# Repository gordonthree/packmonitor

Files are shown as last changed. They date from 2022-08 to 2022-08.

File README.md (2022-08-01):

# Smart battery power monitor project

### A slim circuit board for managing charge and discharge of multi-cell LiFePo4 battery packs. Intended to track state of charge by coulomb counting and prevent battery pack damage from over discharge, over current and over temperature conditions.

## Goals:

1. Monitor and record total amperage in and out
2. Monitor and record temperature, ideally three places
3. Monitor and record pack voltage
4. Provide under-voltage disconnect
5. Provide over-temperature disconnect

## Features:
1. Atmel AVR Micro: ATMEGA4808 TQFP-32
1. Hall effect current sensor: TMCS1108
   * Check my inventory for ACS7xx sensors!
3. FRAM data storage : I2C FM24C64B
4. Precision ADC: I2C NAU7802
5. Hot swap buffer: I2C TCA4311a, PCA9508
1. Host side i2c mux: PCA9545A
6. Max PCB width 18mm
7. Precision fixed resistor for thermistors?
   * Thermistors: NRL1504F3950B1F
   * Thermistors connect to uC ADC
8. Power selector IC: AP2411
9. Low Iq power supply for battery side, switching or linear?
10. SMT button for battiery status

## Connectors:

1. Battery side
   * Battery In and Out (14 ga) - WAGO screw cage
   * 6-pin jst-xh vertical for three thermistors
1. Upstream interface: I2C
   * JST-xh 6-pin connector +5v, GND, SCL, GND, SDA, GND
   * TCA4311 on battery side
   * I2C switch on host side (might not need)

## Indicators:

1. Bus controlled:
   * Bus power (from vcc)
   * Bus active (from CS line)
2. uC controlled:
   * Battery SOC (three leds)
   * Battery health (red/green)

## Client Commands:

* See registers.md for addressing and more details

## Questions:

1. Data logging without a RTC?
  * Chip seems to keep time well enough with occasional updates from master
1. High side or low side disconnect?

## Resources:

#### ATMega4808:

* [https://www.digikey.com/en/products/detail/microchip-technology/ATMEGA4808-AUR/10444912](https://www.digikey.com/en/products/detail/microchip-technology/ATMEGA4808-AUR/10444912)
* [https://ww1.microchip.com/downloads/en/DeviceDoc/ATmega4808-09-DataSheet-DS40002173C.pdf](https://ww1.microchip.com/downloads/en/DeviceDoc/ATmega4808-09-DataSheet-DS40002173C.pdf)
* [https://github.com/MCUdude/MegaCoreX#pinout](https://github.com/MCUdude/MegaCoreX#pinout)

#### Thermistor:

* [https://www.digikey.com/en/products/detail/eaton-electronics-division/NRL1504F3950B1F/15927588](https://www.digikey.com/en/products/detail/eaton-electronics-division/NRL1504F3950B1F/15927588)
* [https://www.maximintegrated.com/en/design/technical-documents/app-notes/1/1753.html](https://www.maximintegrated.com/en/design/technical-documents/app-notes/1/1753.html)
* [https://www.jameco.com/Jameco/workshop/TechTip/temperature-measurement-ntc-thermistors.html](https://www.jameco.com/Jameco/workshop/TechTip/temperature-measurement-ntc-thermistors.html)

#### Readng precise voltages:

* [https://skillbank.co.uk/arduino/measure.htm](https://skillbank.co.uk/arduino/measure.htm)

#### ATMEGA Arduino:

* [https://github.com/MCUdude/MegaCoreX](https://github.com/MCUdude/MegaCoreX)

#### AVR DA / DB / DD Series:

* [https://github.com/SpenceKonde/DxCore](https://github.com/SpenceKonde/DxCore)
#### Bootloader:

* [https://github.com/Optiboot/optiboot](https://github.com/Optiboot/optiboot)

#### FRAM:

* [FM24C64B](https://www.digikey.com/en/products/detail/cypress-semiconductor-corp/FM24C64B-GTR/3788931)

#### Hall Effect Sensor:

* [https://www.ti.com/product/TMCS1108](https://www.ti.com/product/TMCS1108)

#### Hot swap buffers:

* [https://www.digikey.com/en/products/detail/nxp-usa-inc/PCA9545AD-118/789953](https://www.digikey.com/en/products/detail/nxp-usa-inc/PCA9545AD-118/789953)

* [https://www.ti.com/product/TCA4311A?qgpn=tca4311a](https://www.ti.com/product/TCA4311A?qgpn=tca4311a)
#### Switching regulator (tiny):

* [https://www.diodes.com/assets/Datasheets/AP62200_AP62201_AP62200T.pdf](https://www.diodes.com/assets/Datasheets/AP62200_AP62201_AP62200T.pdf)

#### ADC:

* [https://www.nuvoton.com/export/resource-files/NAU7802%20Data%20Sheet%20V1.7.pdf](https://www.nuvoton.com/export/resource-files/NAU7802%20Data%20Sheet%20V1.7.pdf)

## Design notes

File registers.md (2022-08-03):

# Programming registers for packmonitor controller

## These registers are identified by a single command byte and zero or more data bytes

#### 0x00 to 0x20

* (reserved)

#### 0x21 Set high-current limit (unsigned int)

* Set in milliamps, range 0 to 65535 
* Default is 10000 (10a)

#### 0x22 Set high-temp limit (unsigned int)

* Set in millidegrees C, range 0 to 65535 or 65.535c
* Default 45000 or 45c
* Send data as char string

#### 0x23 Set low-temp limit (int / signed 16-bit)

* Set in millidegrees C, range -32768 to 32767 or -32.768c to 32.767c
* Default 0c
* Send data as char string

#### 0x24 Set pack high-voltage limit in millivolts (unsigned int)

* valid range 9600 to 26000, values outside this range will be ignored
* default 14800
* Send data as char string

#### 0x25 Set pack low-voltage limit in millivolts (unsigned int)

* valid range 600 to 26000, values outside this range will be ignored
* default 10800 or 10.8 volts
* Send data as char string

#### 0x26 Set config0 bits (byte) (0 disabled, 1 enabled)

* Bit 7: Disable all protection (default 0)
  * 1: Monitor pack only, ignore all fault conditions
  * 0: Monitor fault conditions as configured (default)
* Bit 6: Over-current protection
  * 1: Disconnect pack when current draw exceeds set-point (default)
  * 0: Disable over-current protection
* Bit 5: Over-temperature protection
  * 1: Disconnect pack when temperature above set-point (default)
  * 0: Ignore low temperature condition
* Bit 4: Under-temperature protection
  * 1: Disconnect pack when temperature below set-point
  * 0: Ignore low temperature condition (default)
* Bit 3: Under-voltage protection
  * 1: Disconnect pack when voltage below set point (default)
  * 0: Ignore under-voltage condition
* Bit 2: Over-voltage protection
  * 1: Disconnect pack when voltage exceeds set point
  * 0: Ignore over-voltage conditions (default)
* Bit 1: (reserved)
* Bit 0: Enable status leds
  * 1: Status LEDs work with button (default)
  * 0: Status LEDs disabled

#### 0x27 Set config1 bits (byte)

* Bit 0 to 7: (reserved)

#### 0x28 Set config2 bits (byte)

* Bit 0 to 7: (reserved)

#### 0x29 Read config0 (byte)

* See set config0 for details

#### 0x2A Read config1 (byte)

* See set config1 for details

#### 0x2B Read config2 (byte)

* See set config2 for details

#### 0x2C Read status0 bites

* Bit 7: Config set
* Bit 6: Time set
* Bit 5: Temperature warning (within 3 deg of limits)
* Bit 4: Current warning (within 1 amps of limit)
* Bit 3: Voltage warning (within 250mV of limits)
* Bit 2: T-sense out of range
* Bit 1: I-sense out of range
* Bit 0: V-sense out of range

#### 0x2D Read status1 bits

#### 0x2E through 0x2F

* (reserved)

#### 0x30 Clear coulomb counter, no data

* Reset coulomb counter

#### 0x31 Read coulomb counter. returns float as char* array

* Shows surplus amps in, or deficit amps out

#### 0x32 Clear total amps counter, except lifetime, returns float as char* array

#### 0x33 Read load amperage, returns float as char* array

* Current load in amps

#### 0x34 Read total pack amps in, returns float as char* array

#### 0x35 Read total pack amps out, returns float as char* array

#### 0x36 Read lifetime amps in, returns float as char* array

#### 0x37 Read lifetime amps out, returns float as char* array

#### 0x38 Clear voltage memory, no data

#### 0x39 Read pack voltage, returns float as char* array

* Returns the current pack voltage in volts

#### 0x3A Read lowest voltage memory, returns float as char* array

* Lowest voltage seen since last clear in volts

#### 0x3B Read lowest voltage timestamp, unsigned long

* Timestamp for when the lowest voltage was recorded

#### 0x3C Read highest voltage memory, returns float as char* array

* Highest voltage seen since last clear in volts

#### 0x3D Read highest voltage timestamp, unsigned long

* Timestamp for when the highest voltage was recorded

#### 0x3E Read bus voltage, returns float as char* array

* Returns the current bus voltage in volts

#### 0x3F 

* (reserved)

#### 0x40 Clear temperature memories, no data

#### 0x41 Read T0 thermistor, returns float as char* array

#### 0x42 Read T0 lowest, returns float as char* array

#### 0x43 Read T0 highest, returns float as char* array

#### 0x44 Read T1 thermistor, returns float as char* array

#### 0x45 Read T1 lowest, returns float as char* array

#### 0x46 Read T1 highest, returns float as char* array

#### 0x47 T0 lowest memory timestamp, unsigned long

#### 0x48 T1 lowest memory timestamp, unsigned long

#### 0x49 T0 highest memory timestamp, unsigned long

#### 0x4A T1 highest memory timestamp, unsigned long

#### 0x4B through 0x4F

* (reserved)

#### 0x50 Clear disconnect history

#### 0x51 Read total over-current disconnects (usigned int)

#### 0x52 Read total under-voltage disconnects (usigned int)

#### 0x53 Read total over-voltage disconnects (usigned int)

#### 0x54 Read total under-temp disconnects (usigned int)

#### 0x55 Read total over-temp disconnects (usigned int)

#### 0x56 Read last disconnect timestamp (ulong)

#### 0x57 Read last disconnect reason code (byte)

#### 0x58 through 0x5F

* (reserved)

#### 0x60 Set time (char *)

* Tranfer time from master to slave
* Expects unix timestamp sent as char string

#### 0x61 Read first-initialized timestamp ulong

#### 0x62 Read current timestamp ulong

#### 0x63 Read time since last sync ulong

#### 0x64 Read uptime ulong

#### 0x65 through 0xFF

* (reserved)

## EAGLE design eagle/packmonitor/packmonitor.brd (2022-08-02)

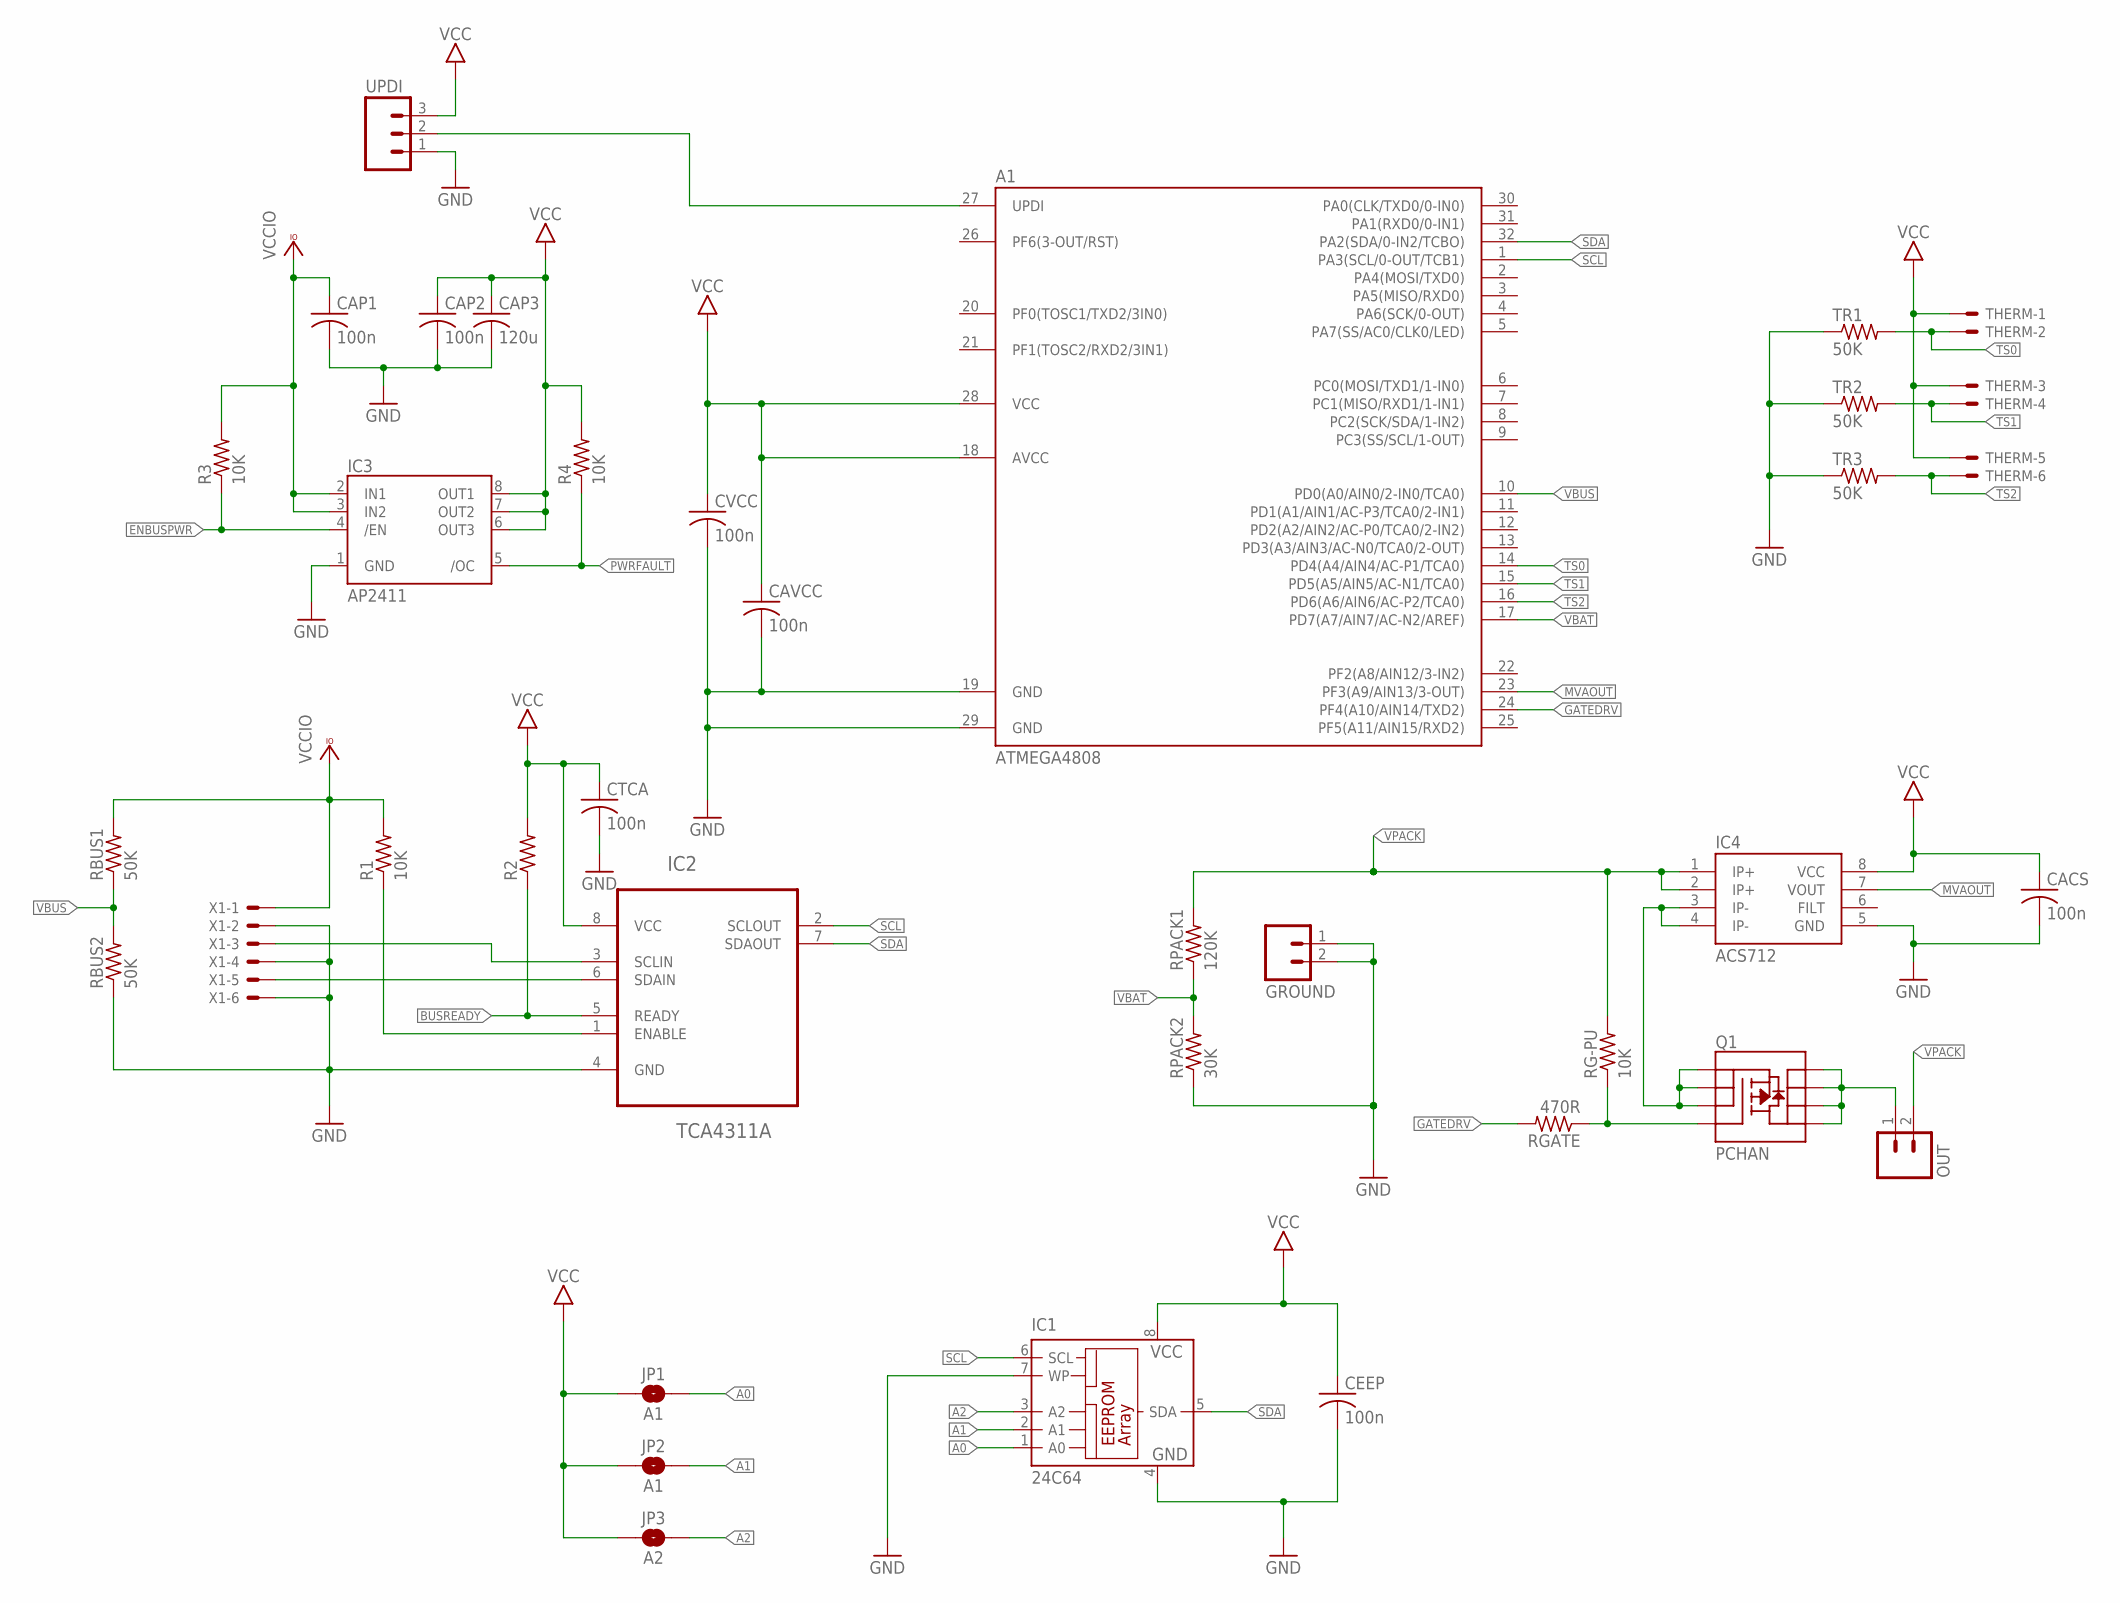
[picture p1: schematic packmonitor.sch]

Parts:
A1: ATMEGA4808; TQFP32-08
CACS: 100n; C0603
CAP1, CAP2: 100n; C0603
CAP3: 120u; C1206
CAVCC: 100n; C0603
CEEP: 100n; C0603
CTCA: 100n; C0603
CVCC: 100n; C0603
GROUND: M023.5MM; SCREWTERMINAL-3.5MM-2
IC1: 24C64; SO-08
IC2: TCA4311A; SOIC127P600X175-8N
IC3: AP2411; SO08
IC4: ACS712; SO08
JP1, JP2: A1; SMT-JUMPER_2_NO_SILK
JP3: A2; SMT-JUMPER_2_NO_SILK
OUT: M023.5MM; SCREWTERMINAL-3.5MM-2
Q1: PCHAN; SO08
R1, R3, R4: 10K; R0603
R2: R-US_R0603; R0603
RBUS1, RBUS2: 50K; R0805
RG-PU: 10K; R0603
RGATE: 470R; R0603
RPACK1: 120K; R0805
RPACK2: 30K; R0805
THERM: JST-XH-06-PIN-ROUND-PAD; JST-XH-06-PACKAGE-ROUND-PAD
TR1, TR2, TR3: 50K; R0805
UPDI: M03PTH; 1X03
X1: JST-XH-06-PIN-LONG-PAD; JST-XH-06-PACKAGE-LONG-PAD

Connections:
A0: IC1.1 (A0), JP1.2
A1: IC1.2 (A1), JP2.2
A2: IC1.3 (A2), JP3.2
BUSREADY: IC2.5 (READY), R2.1
ENBUSPWR: IC3.4 (/EN), R3.1
GATE: Q1.4 (G), RG-PU.1, RGATE.1
GATEDRV: A1.24 (PF4(A10/AIN14/TXD2)), RGATE.2
GND: A1.19 (GND), A1.29 (GND), CACS.2, CAP1.2, CAP2.2, CAP3.2, CAVCC.2, CEEP.2, CTCA.2, CVCC.2, GROUND.1, GROUND.2, IC1.4 (GND), IC1.7 (WP), IC2.4 (GND), IC3.1 (GND), IC4.5 (GND), RBUS2.1, RPACK2.1, TR1.1, TR2.1, TR3.1, UPDI.1, X1.2, X1.4, X1.6
MVAOUT: A1.23 (PF3(A9/AIN13/3-OUT)), IC4.7 (VOUT)
unnamed: IC2.6 (SDAIN), X1.5
unnamed: IC2.3 (SCLIN), X1.3
unnamed: IC2.1 (ENABLE), R1.1
P+IN: IC4.3 (IP-), IC4.4 (IP-), Q1.1 (S), Q1.2 (S), Q1.3 (S)
P+OUT: OUT.1, Q1.5 (D), Q1.6 (D), Q1.7 (D), Q1.8 (D)
PWRFAULT: IC3.5 (/OC), R4.1
SCL: A1.1 (PA3(SCL/0-OUT/TCB1)), IC1.6 (SCL), IC2.2 (SCLOUT)
SDA: A1.32 (PA2(SDA/0-IN2/TCBO)), IC1.5 (SDA), IC2.7 (SDAOUT)
TS0: A1.14 (PD4(A4/AIN4/AC-P1/TCA0)), THERM.2, TR1.2
TS1: A1.15 (PD5(A5/AIN5/AC-N1/TCA0)), THERM.4, TR2.2
TS2: A1.16 (PD6(A6/AIN6/AC-P2/TCA0)), THERM.6, TR3.2
UPDI: A1.27 (UPDI), UPDI.2
VBAT: A1.17 (PD7(A7/AIN7/AC-N2/AREF)), RPACK1.1, RPACK2.2
VBUS: A1.10 (PD0(A0/AIN0/2-IN0/TCA0)), RBUS1.1, RBUS2.2
VCC: A1.18 (AVCC), A1.28 (VCC), CACS.1, CAP2.1, CAP3.1, CAVCC.1, CEEP.1, CTCA.1, CVCC.1, IC1.8 (VCC), IC2.8 (VCC), IC3.6 (OUT3), IC3.7 (OUT2), IC3.8 (OUT1), IC4.8 (VCC), JP1.1, JP2.1, JP3.1, R2.2, R4.2, THERM.1, THERM.3, THERM.5, UPDI.3
VCCIO: CAP1.1, IC3.2 (IN1), IC3.3 (IN2), R1.2, R3.2, RBUS1.2, X1.1
VPACK: IC4.1 (IP+), IC4.2 (IP+), OUT.2, RG-PU.2, RPACK1.2

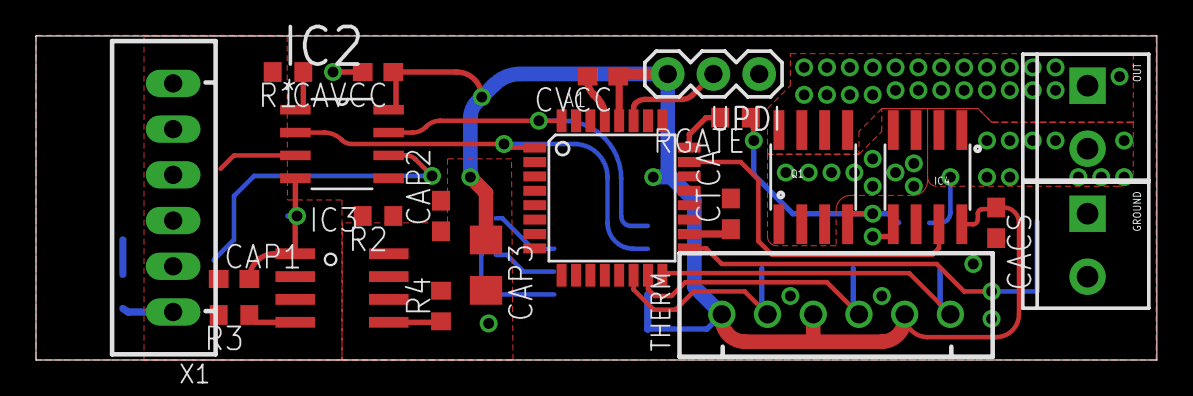
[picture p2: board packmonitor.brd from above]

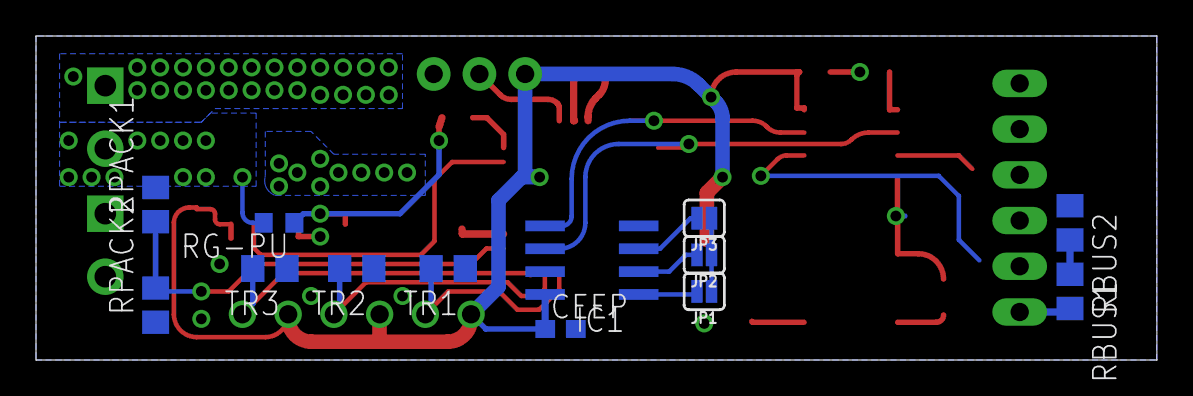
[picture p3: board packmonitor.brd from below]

Board: 2 copper layers, 62.3 x 18.0 mm, 35 parts (13 on the bottom side), 26 nets.

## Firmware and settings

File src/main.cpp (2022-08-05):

#include <Arduino.h>
#include <Wire.h>
#include <packmonlib.h>
#include <time.h>
#include <TimeLib.h>
#include "pm_pins.h"
#include "pm_struct.h"

volatile bool unknownCmd       = false;                  // flag indicating unknown command received
volatile bool txtmsgWaiting    = false;                  // flag indicating message from master is waiting
volatile bool reqEvnt          = false;                  // flag set when the requestEvent ISR fires
volatile bool recvEvnt         = false;                  // flag set when the receiveEvent ISR fires
volatile bool mastersetTime    = false;                  // flag that is set when master has sent time
volatile bool txdataReady      = false;                  // flag that is set when data is ready to send to master
volatile bool purgeTXBuffer    = true;                   // tell loop() to clear the TX buffer
volatile bool purgeRXBuffer    = true;                   // tell loop() to clear the RX buffer
volatile char txtMessage[50];                            // alternate buffer for message from master

volatile uint8_t messageLen    = 0;                      // message from master length
volatile time_t lasttimeSync   = 0;                      // when's the last time master sent us time?
volatile time_t firsttimeSync  = 0;                      // record the timestamp after boot

#ifdef MEGACOREX
#pragma message "Compiled using MegaCoreX!"
#endif

#ifdef I2C_SLAVE_ADDR
#pragma message "Slave address found in build flag"
#else
#pragma message "Slave address NOT FOUND in build flag, defaulting to 0x40"
#define I2C_SLAVE_ADDR 0x40
#endif

#ifdef MCU_ATMEGA328P
#pragma message "Compiling for ATmega328P"
#define SERIALBAUD 115200
#elif MCU_NANOEVERY
#pragma message "Compiling for Nano Every"
#define SERIALBAUD 921600
#elif MCU_AVR128DA28
#pragma message "Compiling for AVR128DA28"
#define SERIALBAUD 921600
#elif MCU_AVR128DA32
#pragma message "Compiling for AVR128DA32"
#define SERIALBAUD 921600
#else
#define SERIALBAUD 115200
#pragma message "Compiling for Unknown MCU"
#endif

PackMonLib toolbox();

char buff[200];

// function to eventually save data to on board FRAM
void writeFRAMuint(uint8_t myAddr, uint32_t myData) { 

}

void writeFRAMint(uint8_t myAddr, int32_t myData) { 

}

// function to read byte from FRAM
uint8_t readFRAMbyte(uint8_t myAddr) { 

}

// function to read uint from FRAM
uint32_t readFRAMuint(uint8_t myAddr) { 
  uint32_t framData = 0;
  if (myAddr==0x39) { // pack voltage
    framData = adcDataBuffer[2].adcRaw;
  } else if (myAddr==0x3E) { // bus voltage
    framData = adcDataBuffer[1].adcRaw;
  } else if (myAddr==0x33) { // active current
    framData = adcDataBuffer[0].adcRaw;
  }
  return framData;
}

// function to read uint from FRAM (eventually)
float readFRAMfloat(uint8_t myAddr) { 
  float framData = 0.0;
  if (myAddr==0x39) { // pack voltage
    framData = adcDataBuffer[2].Volts;
  } else if (myAddr==0x3E) { // bus voltage
    framData = adcDataBuffer[1].Volts;
  } else if (myAddr==0x33) { // active current
    framData = adcDataBuffer[0].Amps;
  }
  return framData;
}


// function to read ulong from FRAM
uint32_t readFRAMulong(uint8_t myAddr) { 

}

// function to read int from FRAM
int16_t readFRAMint(uint8_t myAddr) { 

}

long readADC(uint8_t adcPin, uint8_t noSamples) {
  uint32_t adcResult = 0;
  int      sample    = 0;
  uint8_t  adcX      = 0;
// #ifdef MCU_NANOEVERY
//   analogReference(INTERNAL4V3);  // enable interal 4.3v reference on the Every
// #endif

  for (int x=0; x < noSamples; x++) {
    sample = analogRead(adcPin);                    // sample adc pin
    adcResult = adcResult + sample;                 // add sample for averaging
    delayMicroseconds(250);
  }
  
  adcResult = adcResult / noSamples;
  
  return (long) adcResult;
}

void clearTXBuffer() {
  uint16_t myPtr = 0;
  while (myPtr < txBufferSize) {
    txData.cmdData[myPtr] = '\0';
    myPtr++;
  }
  purgeTXBuffer = false;
}

void clearRXBuffer() {
  uint16_t myPtr = 0;
  rxData.cmdAddr = 0;
  while (myPtr < rxBufferSize) {
    rxData.cmdData[myPtr] = '\0';
    myPtr++;
  }
  purgeTXBuffer = false;
}

// function that executes whenever data is requested by master
// this function is registered as an event, see setup()
void requestEvent() {   
  char reqBuff[80];                          // master has requested data
  if (txdataReady) {
    Wire.write((char *) txData.cmdData, txData.dataLen);          // dump entire tx buffer to the bus, master will read as many bytes as it wants
    txdataReady = false;                          // clear tx flag
    // sprintf(reqBuff, "Request even triggered. Sent: %s", txData.cmdData);
    // Serial.println(reqBuff);
  } else {
    sprintf((char) txData.cmdData,"Slave 0x%X ready!", I2C_SLAVE_ADDR);
    Wire.write((char) txData.cmdData);                         // didn't have anything to send? respond with message of 6 bytes
    // Serial.println((char) txData.cmdData);
  }
  reqEvnt = true;                                 // set flag that we had this interaction
  purgeTXBuffer=true;                                // purge TX buffer
}

// function that executes whenever data is received from master
// this function is registered as an event, see setup()
void receiveEvent(size_t howMany) {
  uint8_t   _isr_masterByte  = 0;
  uint16_t  _isr_masterUint  = 0;
  int16_t   _isr_masterInt   = 0;
  uint32_t  _isr_masterUlong = 0;
  int32_t   _isr_masterLong  = 0;
  uint32_t  _isr_timeStamp   = 0;


  Wire.readBytes( (uint8_t *) &rxData,  howMany);                  // transfer everything from buffer into memory
  rxData.dataLen = howMany - 1;                                    // save the data length for future use
  // sprintf(buff, "RX cmd 0x%X plus %u data bytes\n", rxData.cmdAddr, rxData.dataLen);
  // Serial.print(buff);
  
  rxData.cmdData[howMany] = '\0'; // set the Nth byte as a null
  // for (int xx = 0; xx<howMany; xx++) {
  //   Serial.print(rxData.cmdData[xx]);
  // }
  // Serial.println(" ");

  recvEvnt = true;                                                 // set event flag
  uint8_t _isr_cmdAddr = rxData.cmdAddr;
  
  switch  (_isr_cmdAddr) {
    case 0x00: // no command received
      Serial.println("Address probe detected.");    
    case 0x21: // high current limit, unsigned int
      {
        _isr_masterUint = atol(rxData.cmdData);
        writeFRAMuint(rxData.cmdAddr, _isr_masterUint);
      }
      break;
    case 0x22: // high-temp limit, unsigned int
      {
        _isr_masterUint = atol(rxData.cmdData);
         writeFRAMuint(rxData.cmdAddr, _isr_masterUint);
      }
      break;
    case 0x23: // low-temp limit, signed int
      {
        _isr_masterInt = atoi(rxData.cmdData);
        writeFRAMint(rxData.cmdAddr, _isr_masterInt);
      }
      break;
    case 0x24: // high-voltage limit, unsigned int
      {
        _isr_masterUint = atol(rxData.cmdData);
        writeFRAMuint(rxData.cmdAddr, _isr_masterUint);
      }
      break;
    case 0x25: // low-voltage limit, unsigned int
      {
        _isr_masterUint = atol(rxData.cmdData);
        writeFRAMuint(rxData.cmdAddr, _isr_masterUint);
      }
      break;
    case 0x26: // set config0, byte
      {
        _isr_masterByte = rxData.cmdData[0];
        writeFRAMuint(rxData.cmdAddr, _isr_masterByte);
      }
      break;
    case 0x27: // set config1, byte
      {
        _isr_masterByte = rxData.cmdData[0];
        writeFRAMuint(rxData.cmdAddr, _isr_masterByte);
      }
      break;
    case 0x28: // set config2, byte
      {
        _isr_masterByte = rxData.cmdData[0];
        writeFRAMuint(rxData.cmdAddr, _isr_masterByte);
      }
      break;
    case 0x29: // read config0, byte
      {
        _isr_masterByte = readFRAMbyte(rxData.cmdAddr);
        txData.cmdData[0] = _isr_masterByte;                // store byte in outgoing buffer
        txData.dataLen = 1;                                 // number of bytes to transmit
        txdataReady = true;                                 // set flag we are ready to send data
      }
      break;
    case 0x2A: // read config1, byte
      {
        _isr_masterByte = readFRAMbyte(rxData.cmdAddr);
        txData.cmdData[0] = _isr_masterByte;                // store byte in outgoing buffer
        txData.dataLen = 1;                                 // number of bytes to transmit
        txdataReady = true;                                 // set flag we are ready to send data
      }
      break;
    case 0x2B: // read config2, byte
      {
        _isr_masterByte = readFRAMbyte(rxData.cmdAddr);
        txData.cmdData[0] = _isr_masterByte;                // store byte in outgoing buffer
        txData.dataLen = 1;                                 // number of bytes to transmit
        txdataReady = true;                                 // set flag we are ready to send data
      }
      break;
    case 0x2C: // read status1, byte
      {
        _isr_masterByte = readFRAMbyte(rxData.cmdAddr);
        txData.cmdData[0] = _isr_masterByte;                // store byte in outgoing buffer
        txData.dataLen = 1;                                 // number of bytes to transmit
        txdataReady = true;                                 // set flag we are ready to send data
      }
      break;
    case 0x2D: // read status2, byte
      {
        _isr_masterByte = readFRAMbyte(rxData.cmdAddr);
        txData.cmdData[0] = _isr_masterByte;                // store byte in outgoing buffer
        txData.dataLen = 1;                                 // number of bytes to transmit
        txdataReady = true;                                 // set flag we are ready to send data
      }
      break;
    case 0x2E: // diagnostic turn off LED4
      {
        digitalWrite(LED4, LOW);                            // turn off LED4
      }
      break;
    case 0x2F: // diagnostic turn on LED4
      {
        digitalWrite(LED4, HIGH);                           // turn on LED4
      }
      break;
    case 0x30: // clear coul-counter, no data
      { 
        writeFRAMint(0x31, 0);
      }
      break;
    case 0x31: // read coulomb counter, signed int
      {
        _isr_masterInt = readFRAMint(rxData.cmdAddr);
        ltoa(_isr_masterInt, txData.cmdData, 10);           // store data as char string in tx buffer
        txData.dataLen = 6;                                 // number of bytes to transmit
        txdataReady = true;                                 // set flag we are ready to send data
      }
      break;
    case 0x32: // clear total amps counter, no data
      { 
        writeFRAMint(0x34, 0);
        writeFRAMint(0x35, 0);
      }
      break;
    case 0x33: // read instant amps, signed int
      {
        //_isr_masterInt = readFRAMint(rxData.cmdAddr);
        //ltoa(_isr_masterInt, txData.cmdData, 10);           // store data as char string in tx buffer
        float framData = readFRAMfloat(rxData.cmdAddr);
        dtostrf(framData, 3, 2, txData.cmdData);
        txData.dataLen = 6;                                 // number of bytes to transmit
        txdataReady = true;                                 // set flag we are ready to send data
      }
      break;
    case 0x34: // read total amps in counter, unsigned long
      {
        _isr_masterUlong = readFRAMulong(rxData.cmdAddr);
        ltoa(_isr_masterUlong, txData.cmdData, 10);           // store data as char string in tx buffer
        txData.dataLen = 11;                                 // number of bytes to transmit
        txdataReady = true;                                 // set flag we are ready to send data
      }
      break;
    case 0x35: // read total amps out counter, unsigned long
      {
        _isr_masterUlong = readFRAMulong(rxData.cmdAddr);
        ltoa(_isr_masterUlong, txData.cmdData, 10);           // store data as char string in tx buffer
        txData.dataLen = 11;                                 // number of bytes to transmit
        txdataReady = true;                                 // set flag we are ready to send data
      }
      break;
    case 0x36: // read lifetime amps in, unsigned long
      {
        _isr_masterUlong = readFRAMulong(rxData.cmdAddr);
        ltoa(_isr_masterUlong, txData.cmdData, 10);           // store data as char string in tx buffer
        txData.dataLen = 11;                                 // number of bytes to transmit
        txdataReady = true;                                 // set flag we are ready to send data
      }
      break;
    case 0x37: // read lifetime amps out, ubsigned long 
      {
        _isr_masterUlong = readFRAMulong(rxData.cmdAddr);
        ltoa(_isr_masterUlong, txData.cmdData, 10);           // store data as char string in tx buffer
        txData.dataLen = 11;                                 // number of bytes to transmit
        txdataReady = true;                                 // set flag we are ready to send data
      }
      break;
    case 0x38: // clear voltage memory, no data returned
      { 
        writeFRAMint(0x3A, 0);
        writeFRAMint(0x3B, 0);
        writeFRAMint(0x3C, 0);
        writeFRAMint(0x3D, 0);
      }
      break;
    case 0x39: // read pack voltage, char* array
      {
        // _isr_masterUint = readFRAMuint(rxData.cmdAddr);
        // ltoa(_isr_masterUint, txData.cmdData, 10);           // store data as char string in tx buffer
        float framData = readFRAMfloat(rxData.cmdAddr);
        dtostrf(framData, 3, 2, txData.cmdData);
        txData.dataLen = 6;                                 // number of bytes to transmit
        txdataReady = true;                                 // set flag we are ready to send data
      }
      break;
    case 0x3A: // read lowest voltage memory, unsigned int
      {
        _isr_masterUint = readFRAMulong(rxData.cmdAddr);
        ltoa(_isr_masterUint, txData.cmdData, 10);           // store data as char string in tx buffer
        txData.dataLen = 6;                                 // number of bytes to transmit
        txdataReady = true;                                 // set flag we are ready to send data
      }
      break;
    case 0x3B: // read lowest voltage timestamp, unsigned long
      {
        _isr_masterUlong = readFRAMulong(rxData.cmdAddr);
        ltoa(_isr_masterUlong, txData.cmdData, 10);           // store data as char string in tx buffer
        txData.dataLen = 11;                                 // number of bytes to transmit
        txdataReady = true;                                 // set flag we are ready to send data
      }
      break;
    case 0x3C: // read highest voltage memory, unsigned int
      {
        _isr_masterUint = readFRAMulong(rxData.cmdAddr);
        ltoa(_isr_masterUint, txData.cmdData, 10);           // store data as char string in tx buffer
        txData.dataLen = 6;                                 // number of bytes to transmit
        txdataReady = true;                                 // set flag we are ready to send data
      }
      break;
    case 0x3D: // read highest voltage timestamp, unsigned long
      {
        _isr_masterUlong = readFRAMulong(rxData.cmdAddr);
        ltoa(_isr_masterUlong, txData.cmdData, 10);           // store data as char string in tx buffer
        txData.dataLen = 11;                                 // number of bytes to transmit
        txdataReady = true;                                 // set flag we are ready to send data
      }
      break;
    case 0x3E: // read bus voltage, char* array
      {
        // _isr_masterUint = readFRAMuint(rxData.cmdAddr);
        // ltoa(_isr_masterUint, txData.cmdData, 10);           // store data as char string in tx buffer
        float framData = readFRAMfloat(rxData.cmdAddr);
        dtostrf(framData, 3, 2, txData.cmdData);
        txData.dataLen = 6;                                 // number of bytes to transmit
        txdataReady = true;                                 // set flag we are ready to send data
      }
      break;

    case 0x3F: // print diag message from master
      { 
        strncpy(txtMessage, rxData.cmdData, rxData.dataLen); // copy message into another buffer
        // messageLen = rxData.dataLen; // copy message length too
        txtmsgWaiting = true; // set flag to print the message in loop()
      }
      break;
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
void loop() {
  i++;
  adcUpdateCnt++;

  digitalWrite(LED2, reqEvnt);
  digitalWrite(LED3, recvEvnt);
  digitalWrite(LED4, mastersetTime);

  if (purgeTXBuffer) clearTXBuffer(); 
  if (purgeRXBuffer) clearRXBuffer();

  if (adcUpdateCnt > adcUpdateInterval) {
    long rawAdc    = 0;
    //int acsOffset  = 514;
    float acsmvA  = 0.136;  // 0.136v or 136mV per amp
    float Amps    = 0.0;
    float Volts   = 0.0;
    float sysVcc  = 4.43;
    float vDiv2   = 1.0;
    float vDiv3   = 1.0;
  
// #ifdef MCU_NANOEVERY
//     sysVcc        = 4.300;
// #endif
 
    rawAdc = readADC(ADC0, 20);
    rawAdc = rawAdc;
    //rawAdc = analogRead(ADC0);
    //rawAdc = rawAdc; // subtrack offset
    adcDataBuffer[0].adcRaw = rawAdc;
    Volts = (float)(rawAdc * (sysVcc / 1024.0)) - (sysVcc / 2);
    Amps =  (float)Volts / acsmvA;
    adcDataBuffer[0].Amps  = Amps;
    adcDataBuffer[0].Volts = Volts;
    // Serial.print("0: ");
    // Serial.print(Amps);
    // Serial.print(" 1: ");
    // Serial.print(Volts, 3);
    // Serial.print("v Raw ");
    // Serial.print(rawAdc);
    // Serial.println(" ");

    rawAdc = readADC(ADC1, 20);
    // Serial.print(rawAdc);
    // Serial.print(" <-ADC1 ADC2-> ");
    adcDataBuffer[1].adcRaw   = rawAdc;
    Volts = (float)(rawAdc * (sysVcc / 1024.0)) / vDiv2;
    adcDataBuffer[1].Volts = Volts;

    rawAdc = readADC(ADC2, 20);
    // Serial.println(rawAdc);
    adcDataBuffer[2].adcRaw   = rawAdc;
    Volts = (float)(rawAdc * (sysVcc / 1024.0)) / vDiv3;
    adcDataBuffer[1].Volts = Volts;
    adcUpdateCnt = 0;
  }
  
  if (unknownCmd) {
    unknownCmd = false;

    sprintf(buff, "Command 0x%X: Not recognized\n", rxData.cmdAddr);
    Serial.println(buff);
  }

  if (txtmsgWaiting) {            // print message sent by master
    txtmsgWaiting = false;        // clear flag
    sprintf(buff, "Message from master: %s", txtMessage);
    Serial.println(buff);
  }

  if (i>1000){
    i=0;
    if (timeStatus()==timeSet) {             // print timestamps once time is set
      ledX = ledX ^ 1;              // xor previous state
      digitalWrite(LED1, ledX);     // turn the LED on (HIGH is the voltage level)
      // Serial.printf("Timestamp: %lu\n", now());
    } 
    
    recvEvnt = false; // reset flag
    reqEvnt  = false; // reset flag
  }

  delay(1);
}

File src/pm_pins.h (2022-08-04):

#include <Arduino.h>

#ifdef MCU_ATMEGA328P
#define LED1 PD2
#define LED2 PD3
#define LED3 PD4
#define LED4 PD5

//SDA 18 (A4) SCL 19 (A5)
#define SCL PC5 // A5
#define SDA PC4 // A4

#define ADC0 A1
#define ADC1 A2
#define ADC2 A3
#elif MCU_ATMEGA4808
#define LED1 PF2
#define LED2 PF3
#define LED3 PF4
#define LED4 PF5

#define ADC0 A0
#define ADC1 A2
#define ADC2 A2
// Nano Every: SDA 4 SCL 5 
#define SCL PA3 
#define SDA PA2 
#elif MCU_AVR128DA28
#define LED1 7 // PA0
#define LED2 8 // PA1
#define LED3 9 // PA2
#define LED4 10 // PA3

#define ADC0 13 // PD1
#define ADC1 14 // PD2
#define ADC2 15 // PD3
#define ADC3 16 // PD4
// Nano Every: SDA 4 SCL 5 
#define SCL 3 // PA3
#define SDA 2 // PA2
#elif MCU_AVR128DA32
#define LED1 4 // PA0
#define LED2 5 // PA1
#define LED3 6 // PA2
#define LED4 7 // PA3

#define ADC0 15 // PD1
#define ADC1 16 // PD2
#define ADC2 17 // PD3
#define ADC3 18 // PD3
// Nano Every: SDA 4 SCL 5 
//#define SCL 3 // PA3
//#define SDA 2 // PA2
#elif MCU_NANOEVERY
#define LED1 5 
#define LED2 4
#define LED3 3
#define LED4 2

#define ADC0 15
#define ADC1 16
#define ADC2 17
#define ADC3 18

// Nano Every: SDA 4 SCL 5 
#define SDA 18 
#define SCL 19 
#endif

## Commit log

2022-07-28 Update README.md
    Changed host interface to SPI
2022-07-29 added Eagle related files
    [temp mon with eeprom rev 1.brd, temp mon with eeprom rev 1.sch]
2022-07-29 switched to minicore for mega328p
2022-07-29 adding spi slave code, and more LEDs for blinkin
2022-07-29 spi interrupt firing, but not receiving data yet
2022-07-29 updated build flag to add spi debug led
2022-07-30 could not make SPI work reliably, now i2c
2022-07-30 fleshing out i2c features
2022-07-30 adding i2c complexity
2022-07-30 fixed event handler typo!
    [main.cpp]
2022-07-30 added basic i2c register writes
2022-07-30 removed spi library include
2022-07-31 switched to switch for event handling
2022-07-31 adding registers to switch case
2022-07-31 switch case documented, mostly
2022-07-31 needed curly braces inside every case
2022-07-31 forgot %lu to print a timestamp
2022-07-31 added 4808, updated board for nano
2022-07-31 added options for different boards
2022-07-31 back to i2c part numbers, add links, move stuff
2022-07-31 added i2c switch for host side
2022-07-31 added struct for adc readings
2022-07-31 added more members to adc struct
2022-07-31 added adc pins for mega328
2022-07-31 tinkering with adc
2022-08-01 renamed files
    [packmonitor.brd, packmonitor.sch]
2022-08-01 ADC reading reliably now, floats working i2c
2022-08-01 added 4808 mcu
    [packmonitor.brd, packmonitor.sch]
2022-08-01 slowly adding parts and putting together layout
    [packmonitor.brd, packmonitor.sch]
2022-08-01 added arduino nano every
2022-08-01 slowly adding components
    [packmonitor.brd, packmonitor.sch]
2022-08-01 updated to include packmonitor sub directory
    [packmonitor.brd, packmonitor.sch]
2022-08-01 making good progress on schematic and board layout
    [packmonitor.brd, packmonitor.sch]
2022-08-01 refined connector choice
2022-08-02 added potential adc docu
2022-08-02 making progress slowly
    [packmonitor.brd, packmonitor.sch]
2022-08-02 current and voltage readouts working correctly,
    [main.cpp, pm_struct.h]
2022-08-02 made some good progress on the board this afternoon!
    [packmonitor.brd, packmonitor.sch]
2022-08-02 maybe find the right pin on Every for the built in
2022-08-03 i2c not sending correctly from nanoevery
    [main.cpp, pm_pins.h]
2022-08-03 second slave still having issues sending data
    [main.cpp, pm_struct.h]
2022-08-04 trying to fix jtag upload for m4809 on nano-every
    [main.cpp]
2022-08-04 fixed pins for 128da28, added pins for 128da32
    [pm_pins.h]
2022-08-05 i2c routines moved into their own library
2022-08-05 switching to my own i2c routines library

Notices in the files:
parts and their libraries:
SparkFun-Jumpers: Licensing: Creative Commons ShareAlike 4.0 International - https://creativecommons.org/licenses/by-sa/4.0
